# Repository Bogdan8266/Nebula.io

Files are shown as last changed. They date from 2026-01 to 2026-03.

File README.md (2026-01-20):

# <div align="center"> 🌌 NEBULA <br>  <sub>PORTABLE MODULAR CYBER-DECK PLATFORM</sub></div>  <div align="center">  <!-- BADGES: STATUS & INFO -->    <!-- BADGES: TECH STACK -->     

</div>
  
--- 
## 💀 BRIEFING
 **Nebula** is not just another ESP32 dev-board. It is an ultra-compact, modular handheld platform designed for advanced sensor monitoring, high-current PWM control, and researching airflow dynamics. 
 Built around the **ESP32-S3 WROOM-1**, featuring an Always-On **E-Ink display** and a complex sensor array. The device is powered by a high-density energy stack and encased in a custom shell. 
 > **Disclaimer:** This device includes high-current output drivers. It was designed for educational purposes, pneumatics research, and thermal control experiments. 
 ---
## 📷 3D Render

| 🥛 Semen White | 🍫 Shitty  Brown |
| :---: | :---: |
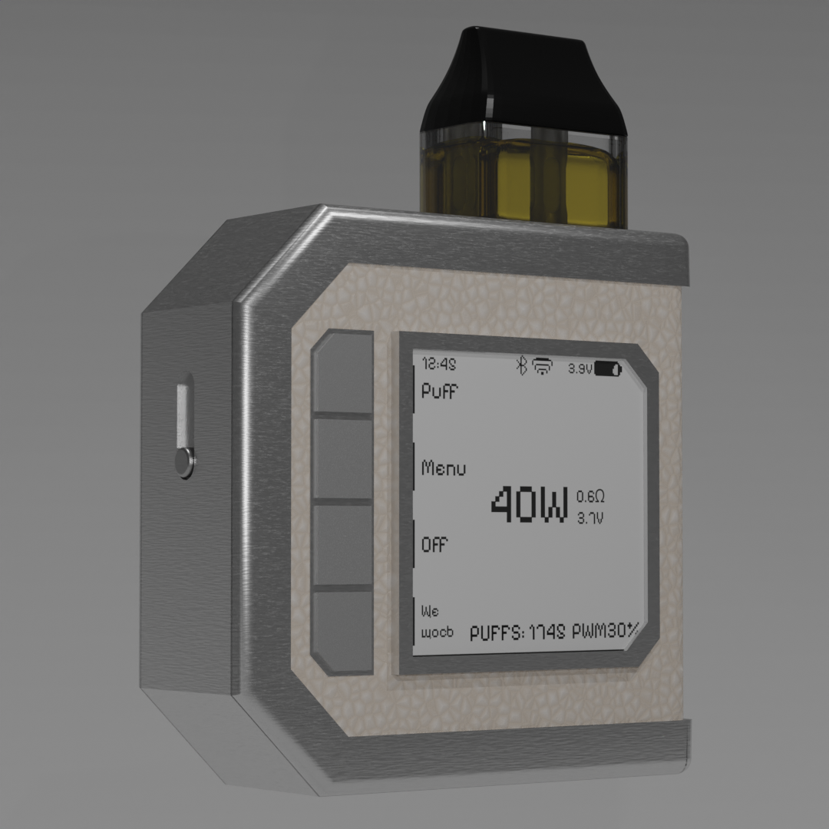
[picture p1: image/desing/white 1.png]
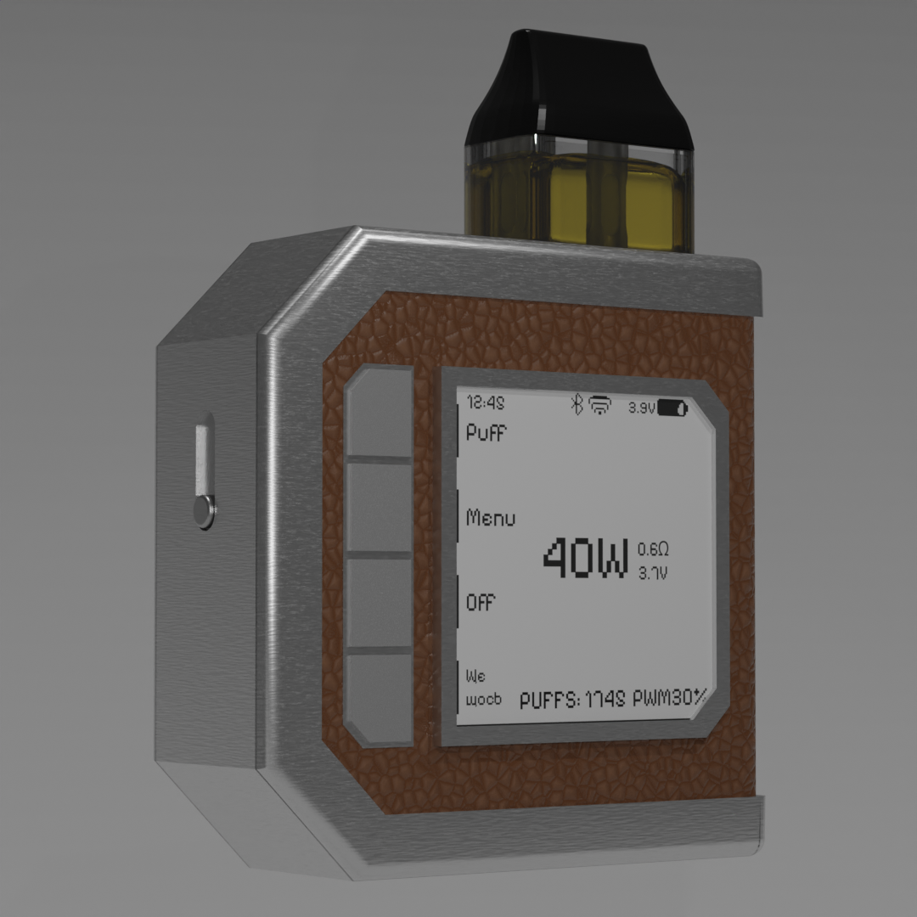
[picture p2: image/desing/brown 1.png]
|  |  |
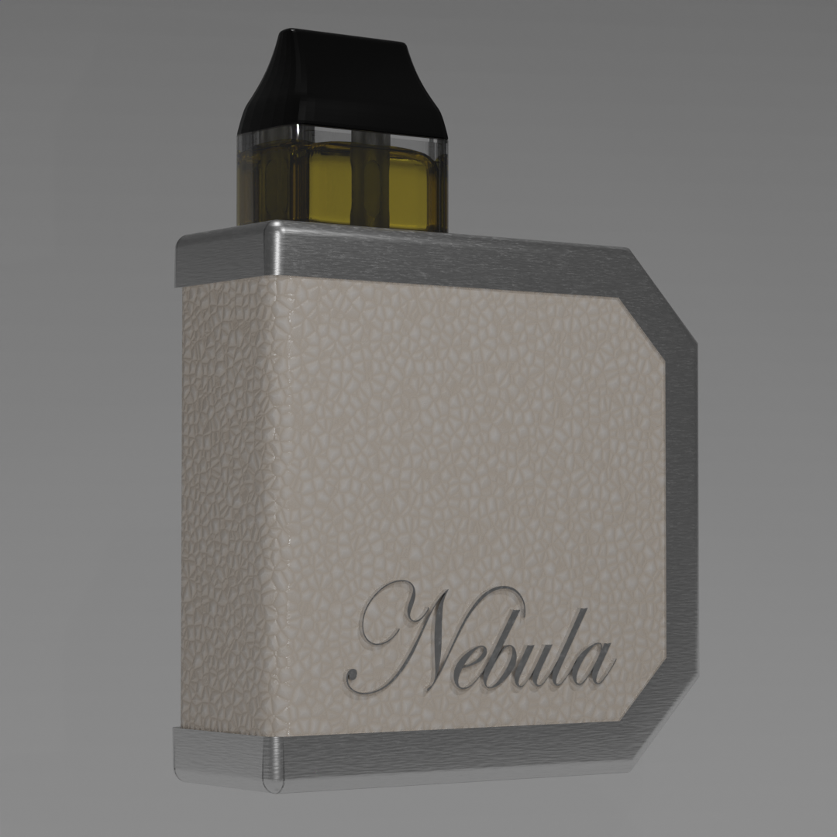
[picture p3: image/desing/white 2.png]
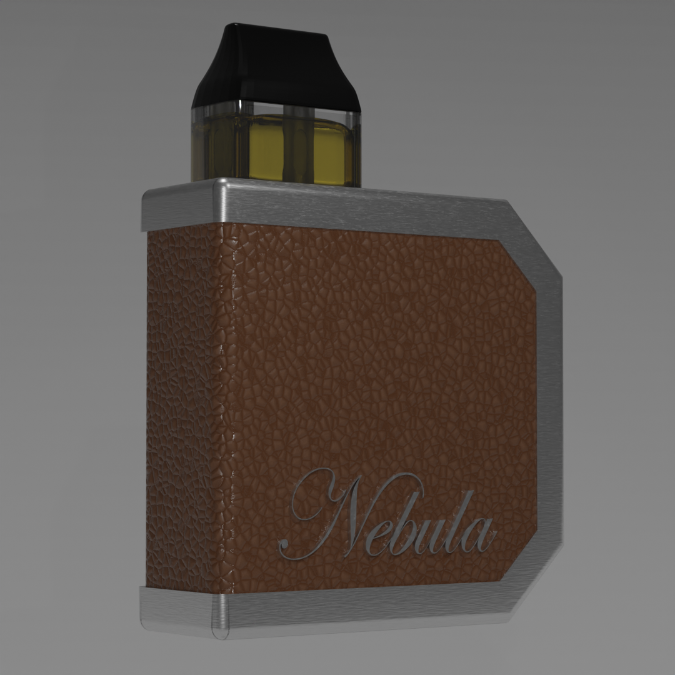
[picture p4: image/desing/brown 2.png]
|  |  |
 
  > *See full gallery in [`/media`](/media) folder.* 
  > ---
  
## 🔧 TECH SPECS 

| Component | Specification | Details |
| :--- | :--- | :--- |
| **🧠 MCU** | **ESP32-S3 WROOM-1** | Dual-Core @ 240MHz, WiFi + BLE 5.0 |
| **👁️ Display** | **1.54" E-Ink** | 200x200px, SSD1681 Driver |
| **🎮 Controls** | **Tactile & IMU** | 4x Switches + Motion/Gestures |
  
---
 ### 📡 Sensor Array (Inputs) 
 1. **Airflow / Pressure:** `BMP388` (Precision Barometric Sensor). Used for pneumatics triggers. 
 2.  **Inertial:** `MPU6050` (6-Axis Gyro + Accelerometer). 
 3.  **Power Mon:** `INA226` (Bi-directional Current/Power Monitor). High-side sensing. 
 4. **Triggers:** Custom analog pneumatic switch (Puff-sensor based). 
 5. **Internal:** Hall Effect & Temperature. 
 ---
 ### ⚡ Power System 
 * **Source:** Li-Po 651732 cell (20C High Drain). 
 * **Charging:** `TP4056` Linear Charger logic. 
   * **Protection:** Hardware voltage dividers + Software Low Voltage Cutoff (LVC). 
   * **Output Stage:** Dual **AO3400 (N-MOSFET)** setup for PWM control of heating elements. 
   * **Storage Gate:** **AO3401 (P-MOSFET)** for hard power-gating the MicroSD card (Deep Sleep optimization). 
---
### 💾 Storage 
* **Slot:** MicroSD (TF Card). 
  * **Format:** FAT32/exFAT. 
  * **Use Case:** Data logging (CSV), OTA Payloads, AOD Image Assets. 
---

## 📱 NEBULA COMPANION APP
*A bleeding-edge mobile application for telemetry and control.*

> [!WARNING]
> **System Requirements:** Android 16 (Baklava) or higher. Only for the brave.

* **Tech Stack:** `Native Android (Kotlin)` + `Jetpack Compose`
* **UI Design:** **Material 3 Expressive**
* **Key Features:** * 📡 **BLE Real-time telemetry** — Stay synced with your hardware.
    * 🎨 **Pixel-Art Editor** — Create custom E-Ink wallpapers.
    * 🚀 **Firmware OTA Updates** — Seamless wireless flashing.
    * 🔗 **"Cyber-Pairing" UX** — Next-gen device discovery.

---

## 🛠️ MANUFACTURE INFO
The PCB pushes the limits of DIY manufacturing with a focus on signal integrity:

| Parameter | Specification |
| :--- | :--- |
| **EDA Tool** | [EasyEDA](https://easyeda.com) |
| **PCB Stack** | **8-Layers** (Signal Integrity & Thermal focus) |
| **Finish** | ENIG (Immersion Gold) |
| **Special Features** | V-Cut daughterboard, Kelvin shunt connections |

### 📂 Technical Assets
* 📥 **[DOWNLOAD GERBER FILES](./hardware/gerbers)** — Ready for production.
* 📑 **[VIEW SCHEMATICS](./hardware/schematics)** — Detailed circuit diagrams.

---

## 📜 LICENSE
This project is open-source and available under the **MIT License**.

> Use it, hack it, build it. Just don't blame me if you burn your sensors. 🔥

---

<div align="center">
  
  <br>
  <i>"Any sufficiently advanced technology is indistinguishable from magic."</i>
  <br>
  <sub>© 1823 Nebula Project</sub>
</div>

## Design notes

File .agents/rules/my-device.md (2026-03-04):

---
trigger: always_on
---

PROJECT: NEBULA - Hi-Fi Modular Cyberdeck Player
SYSTEM CONTEXT & HARDWARE DEFINITION
Device Type: Ultra-compact, modular, handheld Hi-Fi audio player & cyberdeck. Aesthetic/Vibe: Cyberpunk, Industrial, Raw Tech, "Terminal" style UI, Dithering aesthetics, "Slow Tech" philosophy. Core Framework: Arduino (PlatformIO) on ESP32.

🧠 HARDWARE SPECIFICATIONS
1. MCU (Microcontroller):

Model: ESP32..
Key Feature: High-performance caching needed for audio decoding.
2. 👁️ Display (Visual Output):

Panel: 1.54" E-Ink (E-Paper) Display.
Driver: SSD1681.
Resolution: 200 x 200 pixels.
Interface: SPI (4-line SPI: SCK, MOSI, CS, DC, RST, BUSY).
Behavior: Supports Partial Refresh (fast) and Full Refresh. Static UI updates.
3. 💾 Storage (File System):

Media: MicroSD Card (SDXC supported, 128GB+).
Interface: SDMMC 1-bit Mode (Pins: CLK, CMD, D0).
Power Control: Dedicated LDO via GPIO to hard-reset the card for power saving.
File System: FAT32 (via FFat/SdFat) preferred for max compatibility.
4. 🎵 Audio Subsystem (High Fidelity):

DAC: PCM5102A (32-bit, 384kHz, I2S Interface).
Amp: MAX97220 (DirectDrive Headphone Amp, No Output Caps).
I2S Pins: BCK, LRCK, DIN.
Control Pins: XSMT (Soft Mute), SHDN (Amp Shutdown), FLT (Filter), DEMP (De-emphasis).
Headphone Jack: 3.5mm with "Anti-Loop" Hardware Detection (Pin 3 Detect logic).
5. 📡 Sensors & Inputs:

IMU: MPU6050 (Gyro + Accel) via I2C. Used for "Raise to Wake".
Barometer: BMP388 (Precision Pressure) via I2C.
Light Sensor: GL5528 Photoresistor on GPIO13 (ADC2). Used for "Pocket Mode".
Buttons: 4x Tactile Switches connected via ADC Resistor Ladder to a single Analog Pin.
Feedback: LRA Haptic Motor (via L9110S driver).
6. ⚡ Power System:

Battery: Li-Po 1S (3.7V - 4.2V).
Architecture: 3x Discrete XC6220 LDOs (Main, Audio, SD) individually controlled via GPIOs for Deep Sleep optimization.
Charging: IP2312 (High efficiency switching charger).
💻 CURRENT DEVELOPMENT FOCUS: PHASE 1
Goal: Initialize Core System, Display, and Storage. No Audio/Sensors logic yet.

Requirements for Code:

Display: Use GxEPD2 library. Setup for SSD1681 200x200. Implement a "Boot Screen" with a terminal-style loading log (e.g., "MOUNTING SD... OK").
Storage: Initialize SD card in SDMMC 1-bit mode. List files in root directory to Serial Monitor and Display.
UI Style: Monospaced fonts, black background/white text (inverted console style). No animations, discrete updates only.

🎨 UI & UX PHILOSOPHY (The Vibe)
AOD (Always On Display): When sleeping, show a static high-contrast image (Dithered Album Art) + QR Code with Owner Info.
Now Playing: Large Dithered Album Art (background or center), Bold Typography, Status Bar (Battery V/%, Icons).
Navigation: Folder-based structure. Simple lists.

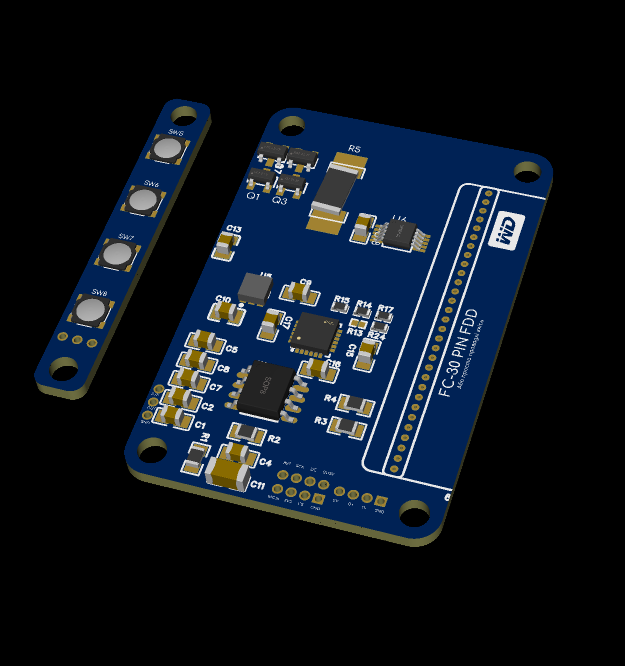
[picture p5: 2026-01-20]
image/PCB/PCB2.png

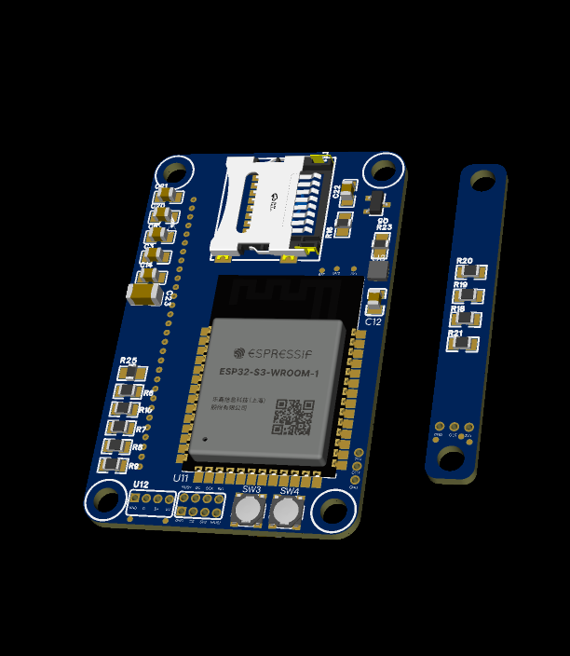
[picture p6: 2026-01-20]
image/PCB/PCB1.png

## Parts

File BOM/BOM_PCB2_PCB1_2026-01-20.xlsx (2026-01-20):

No. | Quantity | Comment | Designator | Footprint | Value | Manufacturer Part | Manufacturer | Supplier Part | Supplier
1 | 3 | 10u | C1,C8,C20 | C0805
2 | 5 | 100n | C2,C3,C6,C7,C21 | C0805
3 | 2 | 10uF | C4,C11 | C0805
4 | 2 | 1u | C5,C23 | C0805
5 | 2 | 10u | C9,C10 | C0805 |  | CL10A105KB8NNNC | SAMSUNG | C15849 | LCSC
6 | 5 | 0.1uF | C12,C14,C15,C17,C18 | C0805
7 | 1 | 1uF | C13 | C0805
8 | 1 | 2200pF | C16 | C0805
9 | 1 | 100nF | C22 | C0805 | 100nF
10 | 4 | AO3400A | Q1,Q3,Q6,Q7 | SOT-23-3_L2.9-W1.3-P1.90-LS2.4-BR |  | AO3400A | AOS | C20917 | LCSC
11 | 1 | AO3401 | Q5 | SOT-23-3_L2.9-W1.4-P1.90-LS2.5-BR |  | AO3401 | GMIC(绿微) | C53261043 | LCSC
12 | 4 | 10k | R1,R4,R23,R25 | R0805
13 | 1 | 1.2k | R2 | R0805
14 | 1 | 100 | R3 | R0805
15 | 1 | 0.002 | R5 | R2512
16 | 2 | 100k | R6,R10 | R0805
17 | 2 | 4.7K | R7,R8 | R0805
18 | 2 | 10K | R9,R16 | R0805
19 | 5 | 0 | R13,R14,R15,R17,R24 | 0402 | 0
20 | 2 | 10K | R18,R21 | R0805 | 10K
21 | 1 | 1K | R19 | R0805 | 1K
22 | 1 | 4.7K | R20 | R0805 | 4.7K
23 | 6 | SWITCH-3.7x3.7x0.35_SMD | SW3,SW4,SW5,SW6,SW7,SW8 | SW-SMD_4P-L3.7-W3.7-P2.75-LS3.7 |  | SWITCH-3.7x3.7x0.35_SMD | BBJ | E19636 | EasyEDA
24 | 1 | TF-CARD XG8P H1.5 | TF1 | TF-SMD_TF-CARD-XG8P-H1.5 |  | TF-CARD XG8P H1.5 | SHOU HAN(首韩) | C7529392 | LCSC
25 | 1 | TP4056-MS | U1 | SOP-8_L4.9-W3.9-P1.27-LS6.0-TL-EP |  | TP4056-MS | MSKSEMI(美森科) | C7473158 | LCSC
26 | 1 | ESP32-S3-WROOM-1 | U2 | ESP32-S3-WROOM-1 |  | ESP32-S3-WROOM-1 | Espressif Systems | ESP32-S3-WROOM-1
27 | 1 | BMP388 | U3 | SENSORM-SMD_BMP388 |  | BMP388 | Bosch(博世) | C779278 | LCSC
28 | 1 | MPU6050_C9900042518 | U4 | QFN-24_L4.0-W4.0-P0.50-BL |  | MPU6050 | null | C9900042518 | LCSC
29 | 1 | XC6220B331MR | U5 | SOT-23-5_L2.9-W1.6-P0.95-LS2.8-BR |  | XC6220B331MR | TECH PUBLIC(台舟) | C3040644 | LCSC
30 | 1 | INA226AQDGSRQ1 | U6 | VSSOP-10_L3.0-W3.0-P0.50-LS4.9-BL |  | INA226AQDGSRQ1 | TI(德州仪器) | C2653835 | LCSC
31 | 1 | 26PIN-dff | U9 | 26PIN-FDD
32 | 1 | Puff sensor | U10 | Puff sensor
33 | 1 | HDR-TH_8P-P0.6 | U11 | HDR-TH_8P-P0.6
34 | 1 | USB-CONNECTOR-OUT | U12 | USB-CONNECTOR-4-PIN

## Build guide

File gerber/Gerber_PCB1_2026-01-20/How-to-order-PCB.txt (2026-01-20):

How to Order PCB

Please refer to:
https://prodocs.easyeda.com/en/pcb/order-order-pcb/index.html

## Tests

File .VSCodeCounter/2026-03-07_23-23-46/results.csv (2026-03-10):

filename | "language" | "C++" | "comment" | "blank" | "total"
/home/bodya/Documents/PlatformIO/Projects/Nebula Os/src/audio/AudioPlayer.h | "C++" | 165 | 3 | 29 | 197
/home/bodya/Documents/PlatformIO/Projects/Nebula Os/src/db/ArtExtractor.h | "C++" | 133 | 11 | 22 | 166
/home/bodya/Documents/PlatformIO/Projects/Nebula Os/src/db/MediaDB.h | "C++" | 158 | 12 | 19 | 189
/home/bodya/Documents/PlatformIO/Projects/Nebula Os/src/db/MediaScanner.h | "C++" | 137 | 15 | 24 | 176
/home/bodya/Documents/PlatformIO/Projects/Nebula Os/src/db/MetaReader.h | "C++" | 249 | 26 | 33 | 308
/home/bodya/Documents/PlatformIO/Projects/Nebula Os/src/db/SettingsManager.h | "C++" | 122 | 3 | 17 | 142
/home/bodya/Documents/PlatformIO/Projects/Nebula Os/src/input/SerialInput.h | "C++" | 22 | 1 | 3 | 26
/home/bodya/Documents/PlatformIO/Projects/Nebula Os/src/led/LEDManager.cpp | "C++" | 98 | 11 | 23 | 132
/home/bodya/Documents/PlatformIO/Projects/Nebula Os/src/led/LEDManager.h | "C++" | 34 | 1 | 10 | 45
/home/bodya/Documents/PlatformIO/Projects/Nebula Os/src/main.cpp | "C++" | 796 | 150 | 144 | 1090
/home/bodya/Documents/PlatformIO/Projects/Nebula Os/src/sensors/MPU6050Manager.h | "C++" | 90 | 7 | 17 | 114
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

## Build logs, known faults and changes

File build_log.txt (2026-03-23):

Processing esp32s3 (platform: espressif32; board: esp32-s3-devkitc-1; framework: arduino)
--------------------------------------------------------------------------------
Tool Manager: Could not parse manifest -> Expecting value: line 1 column 1 (char 0)
Tool Manager: Could not parse manifest -> Expecting value: line 1 column 1 (char 0)
Tool Manager: Could not parse manifest -> Expecting value: line 1 column 1 (char 0)
Tool Manager: Could not parse manifest -> Expecting value: line 1 column 1 (char 0)
Tool Manager: Could not parse manifest -> Expecting value: line 1 column 1 (char 0)
Tool Manager: Could not parse manifest -> Expecting value: line 1 column 1 (char 0)
Tool Manager: Could not parse manifest -> Expecting value: line 1 column 1 (char 0)
Tool Manager: Could not parse manifest -> Expecting value: line 1 column 1 (char 0)
Tool Manager: Could not parse manifest -> Expecting value: line 1 column 1 (char 0)
Tool Manager: Could not parse manifest -> Expecting value: line 1 column 1 (char 0)
Tool Manager: Could not parse manifest -> Expecting value: line 1 column 1 (char 0)
Tool Manager: Could not parse manifest -> Expecting value: line 1 column 1 (char 0)
Verbose mode can be enabled via `-v, --verbose` option
Tool Manager: Could not parse manifest -> Expecting value: line 1 column 1 (char 0)
CONFIGURATION: https://docs.platformio.org/page/boards/espressif32/esp32-s3-devkitc-1.html
PLATFORM: Espressif 32 (6.12.0) > Espressif ESP32-S3-DevKitC-1-N8 (8 MB QD, No PSRAM)
HARDWARE: ESP32S3 240MHz, 320KB RAM, 16MB Flash
DEBUG: Current (esp-builtin) On-board (esp-builtin) External (cmsis-dap, esp-bridge, esp-prog, iot-bus-jtag, jlink, minimodule, olimex-arm-usb-ocd, olimex-arm-usb-ocd-h, olimex-arm-usb-tiny-h, olimex-jtag-tiny, tumpa)
PACKAGES: 
 - framework-arduinoespressif32 @ 3.20017.241212+sha.dcc1105b 
 - tool-esptoolpy @ 2.40900.250804 (4.9.0) 
 - tool-openocd-esp32 @ 2.1100.20220706 (11.0) 
 - toolchain-riscv32-esp @ 8.4.0+2021r2-patch5 
 - toolchain-xtensa-esp32s3 @ 8.4.0+2021r2-patch5
LDF: Library Dependency Finder -> https://bit.ly/configure-pio-ldf
LDF Modes: Finder ~ chain, Compatibility ~ soft
Found 45 compatible libraries
Scanning dependencies...
Dependency Graph
|-- Adafruit BusIO @ 1.17.4
|-- GxEPD2 @ 1.6.7
|-- Adafruit GFX Library @ 1.12.5
|-- U8g2_for_Adafruit_GFX @ 1.8.0
|-- JPEGDEC @ 1.8.4
|-- audio-tools @ 1.2.2+sha.b520706
|-- libfoxenflac @ 1.0.0+sha.4cfa2f5
|-- ESP32-A2DP @ 1.8.9+sha.80d1041
|-- MPU6050 @ 1.4.4
|-- FastLED @ 3.10.3
|-- QRCode @ 0.0.1
|-- ArduinoOTA @ 2.0.0
|-- FS @ 2.0.0
|-- SD_MMC @ 2.0.0
|-- SPI @ 2.0.0
|-- WebServer @ 2.0.0
|-- WiFi @ 2.0.0
|-- Wire @ 2.0.0
Building in release mode
Compiling .pio/build/esp32s3/src/main.cpp.o
<command-line>: warning: "ARDUINO_USB_MODE" redefined
<command-line>: note: this is the location of the previous definition
In file included from .pio/libdeps/esp32s3/ESP32-A2DP/src/BluetoothA2DPSink.h:17,
                 from src/bluetooth/BluetoothManager.h:4,
                 from src/main.cpp:37:
.pio/libdeps/esp32s3/ESP32-A2DP/src/BluetoothA2DPCommon.h:33:4: error: #error "Please read the ESP32-A2DP Wiki about the supported Platforms!"
 #  error "Please read the ESP32-A2DP Wiki about the supported Platforms!"
    ^~~~~
Compiling .pio/build/esp32s3/lib670/GxEPD2/epd3c/GxEPD2_583c.cpp.o
Compiling .pio/build/esp32s3/lib670/GxEPD2/epd3c/GxEPD2_583c_Z83.cpp.o
<command-line>: warning: "ARDUINO_USB_MODE" redefined
<command-line>: note: this is the location of the previous definition
Compiling .pio/build/esp32s3/lib670/GxEPD2/epd3c/GxEPD2_750c.cpp.o
<command-line>: warning: "ARDUINO_USB_MODE" redefined
<command-line>: note: this is the location of the previous definition
Compiling .pio/build/esp32s3/lib670/GxEPD2/epd3c/GxEPD2_750c_GDEW075Z08.cpp.o
<command-line>: warning: "ARDUINO_USB_MODE" redefined
<command-line>: note: this is the location of the previous definition
Compiling .pio/build/esp32s3/lib670/GxEPD2/epd3c/GxEPD2_750c_Z08.cpp.o
<command-line>: warning: "ARDUINO_USB_MODE" redefined
<command-line>: note: this is the location of the previous definition
Compiling .pio/build/esp32s3/lib670/GxEPD2/epd3c/GxEPD2_750c_Z90.cpp.o
<command-line>: warning: "ARDUINO_USB_MODE" redefined
<command-line>: note: this is the location of the previous definition
Compiling .pio/build/esp32s3/lib670/GxEPD2/epd4c/GxEPD2_1160c_GDEY116F51.cpp.o
<command-line>: warning: "ARDUINO_USB_MODE" redefined
<command-line>: note: this is the location of the previous definition
Compiling .pio/build/esp32s3/lib670/GxEPD2/epd4c/GxEPD2_154c_GDEM0154F51H.cpp.o
<command-line>: warning: "ARDUINO_USB_MODE" redefined
<command-line>: note: this is the location of the previous definition
Compiling .pio/build/esp32s3/lib670/GxEPD2/epd4c/GxEPD2_213c_GDEY0213F51.cpp.o
<command-line>: warning: "ARDUINO_USB_MODE" redefined
<command-line>: note: this is the location of the previous definition
Compiling .pio/build/esp32s3/lib670/GxEPD2/epd4c/GxEPD2_266c_GDEY0266F51H.cpp.o
<command-line>: warning: "ARDUINO_USB_MODE" redefined
<command-line>: note: this is the location of the previous definition
<command-line>: warning: "ARDUINO_USB_MODE" redefined
<command-line>: note: this is the location of the previous definition
Compiling .pio/build/esp32s3/lib670/GxEPD2/epd4c/GxEPD2_290c_GDEY029F51H.cpp.o
Compiling .pio/build/esp32s3/lib670/GxEPD2/epd4c/GxEPD2_300c.cpp.o
<command-line>: warning: "ARDUINO_USB_MODE" redefined
<command-line>: note: this is the location of the previous definition
Compiling .pio/build/esp32s3/lib670/GxEPD2/epd4c/GxEPD2_350c_GDEM035F51.cpp.o
<command-line>: warning: "ARDUINO_USB_MODE" redefined
<command-line>: note: this is the location of the previous definition
Compiling .pio/build/esp32s3/lib670/GxEPD2/epd4c/GxEPD2_397c_GDEM0397F81.cpp.o
<command-line>: warning: "ARDUINO_USB_MODE" redefined
<command-line>: note: this is the location of the previous definition
Compiling .pio/build/esp32s3/lib670/GxEPD2/epd4c/GxEPD2_420c_GDEY0420F51.cpp.o
<command-line>: warning: "ARDUINO_USB_MODE" redefined
<command-line>: note: this is the location of the previous definition
Compiling .pio/build/esp32s3/lib670/GxEPD2/epd4c/GxEPD2_437c.cpp.o
<command-line>: warning: "ARDUINO_USB_MODE" redefined
<command-line>: note: this is the location of the previous definition
Compiling .pio/build/esp32s3/lib670/GxEPD2/epd4c/GxEPD2_579c_GDEY0579F51.cpp.o
<command-line>: warning: "ARDUINO_USB_MODE" redefined
<command-line>: note: this is the location of the previous definition
Compiling .pio/build/esp32s3/lib670/GxEPD2/epd4c/GxEPD2_750c_GDEM075F52.cpp.o
<command-line>: warning: "ARDUINO_USB_MODE" redefined
<command-line>: note: this is the location of the previous definition
Compiling .pio/build/esp32s3/lib670/GxEPD2/epd7c/GxEPD2_565c.cpp.o
<command-line>: warning: "ARDUINO_USB_MODE" redefined
<command-line>: note: this is the location of the previous definition
Compiling .pio/build/esp32s3/lib670/GxEPD2/epd7c/GxEPD2_565c_GDEP0565D90.cpp.o
<command-line>: warning: "ARDUINO_USB_MODE" redefined
<command-line>: note: this is the location of the previous definition
Compiling .pio/build/esp32s3/lib670/GxEPD2/epd7c/GxEPD2_730c_ACeP_730.cpp.o
<command-line>: warning: "ARDUINO_USB_MODE" redefined
<command-line>: note: this is the location of the previous definition
<command-line>: warning: "ARDUINO_USB_MODE" redefined
<command-line>: note: this is the location of the previous definition
Compiling .pio/build/esp32s3/lib670/GxEPD2/epd7c/GxEPD2_730c_GDEP073E01.cpp.o
Compiling .pio/build/esp32s3/lib670/GxEPD2/epd7c/GxEPD2_730c_GDEY073D46.cpp.o
<command-line>: warning: "ARDUINO_USB_MODE" redefined
<command-line>: note: this is the location of the previous definition
<command-line>: warning: "ARDUINO_USB_MODE" redefined
<command-line>: note: this is the location of the previous definition
Compiling .pio/build/esp32s3/lib670/GxEPD2/gdem/GxEPD2_1020_GDEM102T91.cpp.o
<command-line>: warning: "ARDUINO_USB_MODE" redefined
<command-line>: note: this is the location of the previous definition
Compiling .pio/build/esp32s3/lib670/GxEPD2/gdem/GxEPD2_1085_GDEM1085T51.cpp.o
In file included from src/main.cpp:37:
src/bluetooth/BluetoothManager.h:68:5: error: 'BluetoothA2DPSink' does not name a type; did you mean 'BluetoothSettings'?
     BluetoothA2DPSink _a2dp_sink;
     ^~~~~~~~~~~~~~~~~
     BluetoothSettings
src/bluetooth/BluetoothManager.h: In member function 'void BluetoothManager::start()':
src/bluetooth/BluetoothManager.h:37:9: error: '_a2dp_sink' was not declared in this scope
         _a2dp_sink.set_pin_config(pin_config);
         ^~~~~~~~~~
Compiling .pio/build/esp32s3/lib670/GxEPD2/gdem/GxEPD2_1330_GDEM133T91.cpp.o
src/bluetooth/BluetoothManager.h: In member function 'void BluetoothManager::stop()':
src/bluetooth/BluetoothManager.h:52:9: error: '_a2dp_sink' was not declared in this scope
         _a2dp_sink.end();
         ^~~~~~~~~~
<command-line>: warning: "ARDUINO_USB_MODE" redefined
<command-line>: note: this is the location of the previous definition
src/bluetooth/BluetoothManager.h: In member function 'void BluetoothManager::setVolume(float)':
src/bluetooth/BluetoothManager.h:62:13: error: '_a2dp_sink' was not declared in this scope
             _a2dp_sink.set_volume(v * 127);
             ^~~~~~~~~~
<command-line>: warning: "ARDUINO_USB_MODE" redefined
<command-line>: note: this is the location of the previous definition
Compiling .pio/build/esp32s3/lib670/GxEPD2/gdem/GxEPD2_397_GDEM0397T81.cpp.o
<command-line>: warning: "ARDUINO_USB_MODE" redefined
<command-line>: note: this is the location of the previous definition
Compiling .pio/build/esp32s3/lib670/GxEPD2/gdem3c/GxEPD2_1330c_GDEM133Z91.cpp.o
<command-line>: warning: "ARDUINO_USB_MODE" redefined
<command-line>: note: this is the location of the previous definition
Compiling .pio/build/esp32s3/lib670/GxEPD2/gdeq/GxEPD2_310_GDEQ031T10.cpp.o
<command-line>: warning: "ARDUINO_USB_MODE" redefined
<command-line>: note: this is the location of the previous definition
Compiling .pio/build/esp32s3/lib670/GxEPD2/gdeq/GxEPD2_426_GDEQ0426T82.cpp.o
<command-line>: warning: "ARDUINO_USB_MODE" redefined
<command-line>: note: this is the location of the previous definition
Compiling .pio/build/esp32s3/lib670/GxEPD2/gdeq/GxEPD2_583_GDEQ0583T31.cpp.o
<command-line>: warning: "ARDUINO_USB_MODE" redefined
<command-line>: note: this is the location of the previous definition
Compiling .pio/build/esp32s3/lib670/GxEPD2/gdeq3c/GxEPD2_583c_GDEQ0583Z31.cpp.o
Compiling .pio/build/esp32s3/lib670/GxEPD2/gdey/GxEPD2_154_GDEY0154D67.cpp.o
<command-line>: warning: "ARDUINO_USB_MODE" redefined
<command-line>: note: this is the location of the previous definition
<command-line>: warning: "ARDUINO_USB_MODE" redefined
<command-line>: note: this is the location of the previous definition
Compiling .pio/build/esp32s3/lib670/GxEPD2/gdey/GxEPD2_213_GDEY0213B74.cpp.o
Compiling .pio/build/esp32s3/lib670/GxEPD2/gdey/GxEPD2_266_GDEY0266T90.cpp.o
<command-line>: warning: "ARDUINO_USB_MODE" redefined
<command-line>: note: this is the location of the previous definition
<command-line>: warning: "ARDUINO_USB_MODE" redefined
<command-line>: note: this is the location of the previous definition
Compiling .pio/build/esp32s3/lib670/GxEPD2/gdey/GxEPD2_270_GDEY027T91.cpp.o
Compiling .pio/build/esp32s3/lib670/GxEPD2/gdey/GxEPD2_290_GDEY029T71H.cpp.o
<command-line>: warning: "ARDUINO_USB_MODE" redefined
<command-line>: note: this is the location of the previous definition
<command-line>: warning: "ARDUINO_USB_MODE" redefined
<command-line>: note: this is the location of the previous definition
Compiling .pio/build/esp32s3/lib670/GxEPD2/gdey/GxEPD2_290_GDEY029T94.cpp.o
<command-line>: warning: "ARDUINO_USB_MODE" redefined
<command-line>: note: this is the location of the previous definition
Compiling .pio/build/esp32s3/lib670/GxEPD2/gdey/GxEPD2_370_GDEY037T03.cpp.o
Compiling .pio/build/esp32s3/lib670/GxEPD2/gdey/GxEPD2_420_GDEY042T81.cpp.o
<command-line>: warning: "ARDUINO_USB_MODE" redefined
<command-line>: note: this is the location of the previous definition
Compiling .pio/build/esp32s3/lib670/GxEPD2/gdey/GxEPD2_579_GDEY0579T93.cpp.o
<command-line>: warning: "ARDUINO_USB_MODE" redefined
<command-line>: note: this is the location of the previous definition
Compiling .pio/build/esp32s3/lib670/GxEPD2/gdey/GxEPD2_750_GDEY075T7.cpp.o
<command-line>: warning: "ARDUINO_USB_MODE" redefined
<command-line>: note: this is the location of the previous definition
<command-line>: warning: "ARDUINO_USB_MODE" redefined
<command-line>: note: this is the location of the previous definition
Compiling .pio/build/esp32s3/lib670/GxEPD2/gdey3c/GxEPD2_1160c_GDEY116Z91.cpp.o
Compiling .pio/build/esp32s3/lib670/GxEPD2/gdey3c/GxEPD2_420c_GDEY042Z98.cpp.o
<command-line>: warning: "ARDUINO_USB_MODE" redefined
<command-line>: note: this is the location of the previous definition
Compiling .pio/build/esp32s3/lib670/GxEPD2/gdey3c/GxEPD2_579c_GDEY0579Z93.cpp.o
<command-line>: warning: "ARDUINO_USB_MODE" redefined
<command-line>: note: this is the location of the previous definition
Compiling .pio/build/esp32s3/lib670/GxEPD2/gdey3c/GxEPD2_750c_GDEY075Z08.cpp.o
<command-line>: warning: "ARDUINO_USB_MODE" redefined
<command-line>: note: this is the location of the previous definition
<command-line>: warning: "ARDUINO_USB_MODE" redefined
<command-line>: note: this is the location of the previous definition
Compiling .pio/build/esp32s3/lib670/GxEPD2/it8951/GxEPD2_it103_1872x1404.cpp.o
Compiling .pio/build/esp32s3/lib670/GxEPD2/it8951/GxEPD2_it60.cpp.o
<command-line>: warning: "ARDUINO_USB_MODE" redefined
<command-line>: note: this is the location of the previous definition
<command-line>: warning: "ARDUINO_USB_MODE" redefined
<command-line>: note: this is the location of the previous definition
Compiling .pio/build/esp32s3/lib670/GxEPD2/it8951/GxEPD2_it60_1448x1072.cpp.o
Compiling .pio/build/esp32s3/lib670/GxEPD2/it8951/GxEPD2_it78_1872x1404.cpp.o
<command-line>: warning: "ARDUINO_USB_MODE" redefined
<command-line>: note: this is the location of the previous definition
Compiling .pio/build/esp32s3/lib670/GxEPD2/other/GxEPD2_420_GYE042A87.cpp.o
<command-line>: warning: "ARDUINO_USB_MODE" redefined
<command-line>: note: this is the location of the previous definition
<command-line>: warning: "ARDUINO_USB_MODE" redefined
<command-line>: note: this is the location of the previous definition
Compiling .pio/build/esp32s3/lib670/GxEPD2/other/GxEPD2_420_SE0420NQ04.cpp.o
<command-line>: warning: "ARDUINO_USB_MODE" redefined
<command-line>: note: this is the location of the previous definition
Compiling .pio/build/esp32s3/lib550/U8g2_for_Adafruit_GFX/U8g2_for_Adafruit_GFX.cpp.o
*** [.pio/build/esp32s3/src/main.cpp.o] Error 1
<command-line>: warning: "ARDUINO_USB_MODE" redefined
<command-line>: note: this is the location of the previous definition
========================== [FAILED] Took 8.62 seconds ==========================

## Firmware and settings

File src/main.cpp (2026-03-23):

/**
 * ╔══════════════════════════════════════════════════╗
 * ║           N E B U L A   O S   v0.1              ║
 * ║    Hi-Fi Modular Cyberdeck Player Firmware       ║
 * ║    Phase 3: Library Menu + Album Art             ║
 * ╚══════════════════════════════════════════════════╝
 *
 * Controls (Serial Monitor 115200):
 *   Menu:       1=UP  2=SELECT  3=DOWN  4=BACK
 *   NowPlaying: 1=PREV  2=PLAY  3=NEXT  4=→Menu
 *   r = Force rescan    d = Dump library
 */

#include <Arduino.h>
#include <SPI.h>
#include <WiFi.h>
#include <WebServer.h>
#include <ArduinoOTA.h>
#include <GxEPD2_BW.h>
#include <Fonts/FreeMonoBold9pt7b.h>
#include <Fonts/FreeMono9pt7b.h>
#include <FS.h>
#include <SD_MMC.h>

#include "input/SerialInput.h"
#include "ui/StatusWidget.h"
#include "ui/NowPlaying.h"
#include "ui/MenuScene.h"
#include "ui/CoverFlowScene.h"
#include "ui/ArtRenderer.h"
#include "ui/MainMenuScene.h"
#include "db/MediaDB.h"
#include "db/MediaScanner.h"
#include "web/WebManager.h"
#include "web/UsbMscManager.h"
#include "audio/AudioPlayer.h"


#include "ui/SettingsScene.h"
#include "ui/SensorsScene.h"
#include "db/SettingsManager.h"
#include "sensors/MPU6050Manager.h"
#include "led/LEDManager.h"
#include "ui/FileExplorerScene.h"
#include "wifi/WiFiScanner.h"
#include "ui/WiFiScene.h"

// ── Wi-Fi ────────────────────────────────────────────────────────
#define WIFI_SSID "Xiaomi_14F8"
#define WIFI_PASS "123456789042"

// ── Pins ─────────────────────────────────────────────────────────
#define EPD_CS    10
#define EPD_DC    17
#define EPD_RST   16
#define EPD_BUSY  18

// ── Audio/Power Placeholders (Future PCB) ────────────────────────
// #define DAC_XSMT  XX // Soft Mute
// #define LDO_EN    XX // 3.3V LDO for Audio/SD

#define SD_MMC_CLK 14
#define SD_MMC_CMD 15
#define SD_MMC_D0  2

// ── Display ───────────────────────────────────────────────────────
using Display = GxEPD2_BW<GxEPD2_154_D67, GxEPD2_154_D67::HEIGHT>;
Display display(GxEPD2_154_D67(EPD_CS, EPD_DC, EPD_RST, EPD_BUSY));

// ── SD + DB ───────────────────────────────────────────────────────
fs::FS&      sd = SD_MMC;
MediaDB      mediaDB;
MediaScanner scanner;

// ── Settings ──────────────────────────────────────────────────────
SystemSettings sysSettings;
SettingsScene  settingsScene;
SensorsScene   sensorsScene;
FileExplorerScene explorerScene;
MPU6050Manager mpuManager;

// ── Scenes ────────────────────────────────────────────────────────
MenuScene<Display>    menu;
CoverFlowScene<Display> coverFlow;
MainMenuScene<Display, fs::FS> mainMenu;
StatusWidget          systemStatus;
NowPlaying<Display>   nowPlaying(display);

enum class AppState { BOOT, MAIN_MENU, COVER_FLOW, SONG_LIST, NOW_PLAYING, SETTINGS, USB_SYNC, SENSORS, FILE_EXPLORER, WIFI_SCANNER };
AppState appState = AppState::BOOT;
NebulaPlayer audioPlayer;
WebManager   webManager(sd);
WiFiScanner  wifiScanner;
WiFiScene    wifiScene;

// Dynamic coloring based on settings
#define CL_BG (sysSettings.display.inverted ? GxEPD_BLACK : GxEPD_WHITE)
#define CL_FG (sysSettings.display.inverted ? GxEPD_WHITE : GxEPD_BLACK)

// К-ть треків у поточному альбомі та поточний індекс для PREV/NEXT
static TrackRecord  currentAlbumTracks[8]; // Reduced from 16 to save 4KB
static uint16_t     currentAlbumTrackCount = 0;
static int16_t      currentTrackIdx        = -1;

// ─────────────────────────────────────────────────────────────────
//  Memory Management for NowPlaying Background
// ─────────────────────────────────────────────────────────────────
static uint8_t* currentNpBgBitmap = nullptr;
static uint32_t trackStartTime = 0;
static uint32_t totalPauseTime = 0;
static uint32_t pauseStartTime = 0;

// ─────────────────────────────────────────────────────────────────
//  Waveform LUT for SSD1681 - Fast vs Quality
// ─────────────────────────────────────────────────────────────────
// Fast LUT: Minimal phases, short times = fast refresh
// Quality LUT: Full phases, proper times = best image quality

// Standard full waveform (from GxEPD2 library, optimized)
static const uint8_t waveformFull[] = {
    // VS settings for each phase (48 phases x 4 LUTs x 2 bits = 384 bits = 48 bytes)
    0x00, 0x00, 0x00, 0x00, 0x00, 0x00, 0x00, 0x00,
    0x00, 0x00, 0x00, 0x00, 0x00, 0x00, 0x00, 0x00,
    0x00, 0x00, 0x00, 0x00, 0x00, 0x00, 0x00, 0x00,
    0x00, 0x00, 0x00, 0x00, 0x00, 0x00, 0x00, 0x00,
    0x00, 0x00, 0x00, 0x00, 0x00, 0x00, 0x00, 0x00,
    0x00, 0x00, 0x00, 0x00, 0x00, 0x00, 0x00, 0x00,
    // TP (time per phase) - 48 bytes
    0x01, 0x01, 0x01, 0x01, 0x02, 0x02, 0x04, 0x04,
    0x08, 0x08, 0x10, 0x10, 0x20, 0x20, 0x40, 0x40,
    0x80, 0x80, 0x00, 0x00, 0x00, 0x00, 0x00, 0x00,
    0x00, 0x00, 0x00, 0x00, 0x00, 0x00, 0x00, 0x00,
    0x00, 0x00, 0x00, 0x00, 0x00, 0x00, 0x00, 0x00,
    0x00, 0x00, 0x00, 0x00, 0x00, 0x00, 0x00, 0x00,
    // RP (repeat count) - 12 bytes
    0x00, 0x00, 0x00, 0x00, 0x00, 0x00, 0x00, 0x00,
    0x00, 0x00, 0x00, 0x00,
    // SR (state repeat) - 24 bytes  
    0x01, 0x01, 0x01, 0x01, 0x01, 0x01, 0x01, 0x01,
    0x01, 0x01, 0x01, 0x01, 0x01, 0x01, 0x01, 0x01,
    0x01, 0x01, 0x01, 0x01, 0x01, 0x01, 0x01, 0x01,
    // FR (frame rate) - 12 bytes
    0x00, 0x00, 0x00, 0x00, 0x00, 0x00, 0x00, 0x00,
    0x00, 0x00, 0x00, 0x00,
    // XON - 3 bytes
    0x00, 0x00, 0x00,
    // EOPT, Gate/Source/VCOM - 5 bytes
    0x02, 0x00, 0x3F, 0x00, 0x00
};

// Fast waveform - fewer phases, shorter times
static const uint8_t waveformFast[] = {
    // VS settings - minimal
    0x00, 0x00, 0x00, 0x00, 0x00, 0x00, 0x00, 0x00,
    0x00, 0x00, 0x00, 0x00, 0x00, 0x00, 0x00, 0x00,
    0x00, 0x00, 0x00, 0x00, 0x00, 0x00, 0x00, 0x00,
    0x00, 0x00, 0x00, 0x00, 0x00, 0x00, 0x00, 0x00,
    0x00, 0x00, 0x00, 0x00, 0x00, 0x00, 0x00, 0x00,
    0x00, 0x00, 0x00, 0x00, 0x00, 0x00, 0x00, 0x00,
    // TP - VERY SHORT for fast refresh!
    0x01, 0x01, 0x01, 0x01, 0x01, 0x01, 0x01, 0x01,
    0x01, 0x01, 0x01, 0x01, 0x01, 0x01, 0x01, 0x01,
    0x00, 0x00, 0x00, 0x00, 0x00, 0x00, 0x00, 0x00,
    0x00, 0x00, 0x00, 0x00, 0x00, 0x00, 0x00, 0x00,
    0x00, 0x00, 0x00, 0x00, 0x00, 0x00, 0x00, 0x00,
    0x00, 0x00, 0x00, 0x00, 0x00, 0x00, 0x00, 0x00,
    // RP
    0x00, 0x00, 0x00, 0x00, 0x00, 0x00, 0x00, 0x00,
    0x00, 0x00, 0x00, 0x00,
    // SR
    0x01, 0x01, 0x01, 0x01, 0x01, 0x01, 0x01, 0x01,
    0x01, 0x01, 0x01, 0x01, 0x01, 0x01, 0x01, 0x01,
    0x01, 0x01, 0x01, 0x01, 0x01, 0x01, 0x01, 0x01,
    // FR
    0x00, 0x00, 0x00, 0x00, 0x00, 0x00, 0x00, 0x00,
    0x00, 0x00, 0x00, 0x00,
    // XON
    0x00, 0x00, 0x00,
    // EOPT, Gate/Source/VCOM
    0x02, 0x00, 0x3F, 0x00, 0x00
};

static bool currentWaveformFast = false;

// Load waveform LUT to SSD1681
void loadWaveformLUT(const uint8_t* lut) {
    // Command 0x32: Write LUT register (153 bytes)
    digitalWrite(EPD_CS, LOW);
    digitalWrite(EPD_DC, LOW);
    SPI.transfer(0x32); // Write LUT
    digitalWrite(EPD_CS, HIGH);
    
    delayMicroseconds(10);
    
    // Send 153 bytes of LUT data
    digitalWrite(EPD_CS, LOW);
    digitalWrite(EPD_DC, HIGH);
    for (int i = 0; i < 153; i++) {
        SPI.transfer(lut[i]);
    }
    digitalWrite(EPD_CS, HIGH);
    
    Serial.println("[WF] LUT loaded");
}

// Apply waveform based on current state
void applyWaveform() {
    bool wantFast = (appState == AppState::MAIN_MENU || 
                    appState == AppState::COVER_FLOW || 
                    appState == AppState::SONG_LIST ||
                    appState == AppState::SETTINGS);
    
    if (wantFast != currentWaveformFast) {
        currentWaveformFast = wantFast;
        const uint8_t* lut = wantFast ? waveformFast : waveformFull;
        loadWaveformLUT(lut);
        Serial.printf("[WF] %s mode (state=%d)\n", wantFast ? "FAST" : "QUALITY", (int)appState);
    }
}

// ─────────────────────────────────────────────────────────────────
//  Charge Pump Voltage Control (SSD1681)
// ─────────────────────────────────────────────────────────────────
void applyChargePumpVoltage() {
    uint8_t vsh1;
    if (appState == AppState::NOW_PLAYING) {
        vsh1 = sysSettings.display.vsh1Media;
    } else {
        vsh1 = sysSettings.display.vsh1Menu;
    }
    
    uint8_t vsh2 = 50; // 5V
    uint8_t vsl = 0x32; // -15V
    
    digitalWrite(EPD_CS, LOW);
    digitalWrite(EPD_DC, LOW);
    SPI.transfer(0x04); // Command 0x04
    
    digitalWrite(EPD_DC, HIGH);
    SPI.transfer(vsh1);
    SPI.transfer(vsh2);
    SPI.transfer(vsl);
    digitalWrite(EPD_CS, HIGH);
    
    Serial.printf("[CP] VSH1=%d.%dV\n", vsh1/10, vsh1%10);
}

// ─────────────────────────────────────────────────────────────────
//  Power Management
// ─────────────────────────────────────────────────────────────────
void applyPowerSettings() {
    uint16_t freq = sysSettings.power.menuFreq;
    if (appState == AppState::NOW_PLAYING) freq = sysSettings.power.musicFreq;
    if (appState == AppState::USB_SYNC) freq = sysSettings.power.usbFreq;
    
    // Safeguard: WiFi/Web needs at least 80MHz to be stable
    if (freq < 80) {
        Serial.printf("[PWR] Freq %d too low for WiFi, forcing 80MHz\n", freq);
        freq = 80;
    }

    setCpuFrequencyMhz(freq);
    Serial.printf("[PWR] CPU Frequency set to %d MHz\n", freq);
}

void enterDeepSleep() {
    Serial.println("[PWR] Entering Deep Sleep...");
    
    // 1. Final Display Update
    display.setFullWindow();
    display.firstPage();
    do {
        display.fillScreen(GxEPD_WHITE);
        display.setFont(nullptr);
        display.setCursor(50, 100);
        display.print("SLEEPING... [BOOT TO WAKE]");
    } while (display.nextPage());
    
    // 2. Wait for E-Ink to finish drawing (critically important!)
    delay(1000); 

    // 3. Turn off LEDs and wait for task
    sysSettings.led.enabled = false;
    sysSettings.led.smoothness = false; // Disable smoothness for instant off
    LEDManager::getInstance().resetIdleTimer(); // Ensure task wakes if it was timed out
    delay(100); // Let LED task process it
    
    // Force clear for safety
    FastLED.clear();
    FastLED.show();
    
    // 4. Persistence
    SettingsManager::save(sd, sysSettings);
    
    // 5. Peripheral Sleep
    mpuManager.setSleep(true);
    SD_MMC.end(); // De-init SD
    
    // 6. Wakeup Setup (GPIO0 is BOOT button)
    esp_sleep_enable_ext0_wakeup(GPIO_NUM_0, 0); 
    
    Serial.flush();
    esp_deep_sleep_start();
}

void clearNpBgBitmap() {
    if (currentNpBgBitmap) {
        free(currentNpBgBitmap);
        currentNpBgBitmap = nullptr;
    }
}

// ─────────────────────────────────────────────────────────────────
//  Boot log (terminal style)
// ─────────────────────────────────────────────────────────────────
static int  logLine  = 0;
static const int LINE_H   = 14;
static const int MARGIN_X =  4;
static const int MARGIN_Y = 12;

void epd_log(const char* text) {
    if (logLine > 11) return;
    int y = MARGIN_Y + logLine++ * LINE_H;
    display.setPartialWindow(0, y - LINE_H + 2, 200, LINE_H);
    display.firstPage();
    do {
        display.fillScreen(GxEPD_BLACK);
        display.setFont(&FreeMonoBold9pt7b);
        display.setTextColor(GxEPD_WHITE);
        display.setCursor(MARGIN_X, y);
        display.print(text);
    } while (display.nextPage());
}

void printBanner() {
    display.setFullWindow();
    display.firstPage();
    do {
        display.fillScreen(GxEPD_BLACK);
        display.setFont(&FreeMonoBold9pt7b);
        display.setTextColor(GxEPD_WHITE);
        display.setCursor(MARGIN_X, MARGIN_Y);         display.print("NEBULA OS v0.1");
        display.setCursor(MARGIN_X, MARGIN_Y + LINE_H); display.print("----------------");
    } while (display.nextPage());
    logLine = 2;
}

// ─────────────────────────────────────────────────────────────────
//  SD + MediaDB
// ─────────────────────────────────────────────────────────────────
bool initSD() {
    SD_MMC.setPins(SD_MMC_CLK, SD_MMC_CMD, SD_MMC_D0);
    // Use 20MHz for stability in 1-bit mode, especially for MSC
    return SD_MMC.begin("/sd", true, false, 20000); 
}

void initMediaDB(bool forceRescan = false) {
    mediaDB.close();
    if (!forceRescan && mediaDB.open(sd)) {
        char buf[48];
        snprintf(buf, sizeof(buf), "DB: %lu tracks", mediaDB.trackCount());
        Serial.println(buf); epd_log(buf);
        return;
    }
    Serial.println("[DB] Building library...");
    epd_log("SCANNING SD...");

    uint32_t t0 = millis();
    uint32_t count = scanner.scan(sd, "/music");
    uint32_t elapsed = (millis() - t0) / 1000;

    char buf[48];
    if (count > 0) {
        snprintf(buf, sizeof(buf), "DB: %lu tracks (%lus)", count, elapsed);
        Serial.println(buf); epd_log(buf);
        mediaDB.open(sd);
    } else {
        epd_log("NO MUSIC FOUND!");
        Serial.println("[DB] No music found");
    }
}

// ─────────────────────────────────────────────────────────────────
//  Scene transitions
// ─────────────────────────────────────────────────────────────────
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
void loop() {
    uint32_t now = millis();

    // Auto-apply power profile and charge pump on state change
    static AppState lastState = AppState::BOOT;
    if (appState != lastState) {
        lastState = appState;
        applyPowerSettings();
        applyChargePumpVoltage();
        applyWaveform();
    }

    // Читати Serial або Web Remote
    char raw = 0;
    if (Serial.available()) {
        raw = Serial.read();
        while (Serial.available()) Serial.read();
    } else {
        raw = webManager.getRemoteKey();
    }

    if (raw != 0) {
        LEDManager::getInstance().resetIdleTimer();
    }


    // Глобальні команди
    if (raw == 'r') {
        Serial.println(">> Force rescan...");
        logLine = 0; printBanner();
        initMediaDB(true);
        switchToMenu();
        return;
    }
    if (raw == 'd') { dumpLibrary(); return; }

    // ── MAIN MENU ────────────────────────────────────────────────
    if (appState == AppState::MAIN_MENU) {
        if      (raw == '1') mainMenu.onPrev();
        else if (raw == '3') mainMenu.onNext();
        else if (raw == '2') {
            uint8_t sel = mainMenu.selectedIndex();
            if (sel == 0) { // MEDIA LIBRARY
                // If audio is playing in background, go back to NowPlaying directly
                if (audioPlayer.isPlaying() && currentAlbumTrackCount > 0) {
                    appState = AppState::NOW_PLAYING;
                    // Redraw NowPlaying with current track art
                    switchToNowPlaying(currentAlbumTracks[currentTrackIdx], currentTrackIdx);
                } else {
                    appState = AppState::COVER_FLOW;
                    coverFlow.setSettings(sysSettings);
                    coverFlow.setColors(CL_FG, CL_BG, sysSettings.display.skipArtInvert);
                    coverFlow.init(mediaDB, display, sd);
                    coverFlow.drawFull();
                }
            }
            else if (sel == 1) { /* TELEMETRY */ }
            else if (sel == 2) { /* EXTRAS */ }
            else if (sel == 3) { // SETTINGS
                appState = AppState::SETTINGS;
                settingsScene.init(display, sd, sysSettings);
                settingsScene.drawFull();
            }
        }
        else if (raw == '4') {
             // Redraw
             mainMenu.drawFull();
        }
    }

    // ── SETTINGS ────────────────────────────────────────────────
    else if (appState == AppState::SETTINGS) {
        if      (raw == '1') settingsScene.onUp();
        else if (raw == '3') settingsScene.onDown();
        else if (raw == '2') {
            settingsScene.onSelect();
            // Check if user selected WiFi Scanner
            if (settingsScene.wantsWiFiScan()) {
                appState = AppState::WIFI_SCANNER;
                wifiScene.init(display, sd, sysSettings, wifiScanner);
                wifiScene.startScan();
            }
            // Check if user selected WiFi Info
            if (settingsScene.wantsWiFiInfo()) {
                appState = AppState::WIFI_SCANNER;
                wifiScene.init(display, sd, sysSettings, wifiScanner);
                wifiScene.showInfo();
            }
            // Check if user selected WiFi QR
            if (settingsScene.wantsWiFiQR()) {
                appState = AppState::WIFI_SCANNER;
                wifiScene.init(display, sd, sysSettings, wifiScanner);
                wifiScene.showQRCode();
            }
            // Check if user selected SENSORS
            if (settingsScene.wantsSensors()) {
                appState = AppState::SENSORS;
                mpuManager.applySettings(sysSettings.mpu);
                sensorsScene.init(display, sysSettings, mpuManager);
                sensorsScene.drawFull();
            }
            if (settingsScene.wantsExplorer()) {
                appState = AppState::FILE_EXPLORER;
                explorerScene.init(display, sd, &sysSettings);
                explorerScene.drawFull();
            }
        }
        else if (raw == '4') {
            if (settingsScene.onBack()) {
                // Apply changes to all components immediately
                audioPlayer.applySettings(sysSettings);
                
                // === Bluetooth Dynamic Switch ===
                
                // ==============================

                mpuManager.applySettings(sysSettings.mpu);
                
                // Apply WiFi changes
                webManager.setWiFiEnabled(sysSettings.wifi.enabled);
                if (sysSettings.wifi.enabled) {
                    webManager.setWebEnabled(sysSettings.wifi.webEnabled);
                    webManager.setOTAEnabled(sysSettings.wifi.otaEnabled);
                }
                
                mainMenu.setColors(CL_FG, CL_BG);
                menu.setColors(CL_FG, CL_BG);
                coverFlow.setColors(CL_FG, CL_BG, sysSettings.display.skipArtInvert);
                nowPlaying.setColors(CL_FG, CL_BG);

                // Re-apply SPI freq if it was changed
                display.init(115200, false, sysSettings.display.spiFreqMhz, false); 

                appState = AppState::MAIN_MENU;
                mainMenu.drawFull();
            }
        }
        else if (raw == '5') {
            if (sysSettings.usb.mode == 0) {
                // SERIAL - Do nothing
            } else if (sysSettings.usb.mode == 1) {
                enterUsbSync();
            } else if (sysSettings.usb.mode == 2) {
                // FLASH (SLOWBOOT)
                uint8_t* flashBitmap = nullptr;
                File f = sd.open("/Bitmaps/Connect.bin", "r");
                if (f) {
                    flashBitmap = (uint8_t*)malloc(5000);
                    if (flashBitmap) f.read(flashBitmap, 5000);
                    f.close();
                }

                display.setFullWindow();
                display.firstPage();
                do {
                    if (flashBitmap) {
                        display.drawBitmap(0, 0, flashBitmap, 200, 200, CL_BG, CL_FG);
                    } else {
                        display.fillScreen(CL_BG);
                    }
                    display.fillRect(0, 0, 200, 25, CL_FG);
                    display.setFont(&FreeMonoBold9pt7b);
                    display.setTextColor(CL_BG);
                    
                    String title = "FIRMWARE FLASH";
                    int16_t x1, y1; uint16_t w, h;
                    display.getTextBounds(title.c_str(), 0, 0, &x1, &y1, &w, &h);
                    display.setCursor((200 - w) / 2, 18);
                    display.print(title);
                } while (display.nextPage());
                
                if (flashBitmap) free(flashBitmap);
                
                delay(1000);
                REG_WRITE(RTC_CNTL_OPTION1_REG, RTC_CNTL_FORCE_DOWNLOAD_BOOT);
                esp_restart();
            }
        }
    }

    // ── SENSORS ──────────────────────────────────────────────────
    else if (appState == AppState::SENSORS) {
        if      (raw == '1') sensorsScene.onUp();
        else if (raw == '3') sensorsScene.onDown();
        else if (raw == '2') sensorsScene.onSelect();
        else if (raw == '4') {
            if (sensorsScene.onBack()) {
                // Return to settings
                appState = AppState::SETTINGS;
                SettingsManager::save(sd, sysSettings);
                settingsScene.init(display, sd, sysSettings);
                settingsScene.drawFull();
            }
        }
        // Tick for 3D cube live updates
        sensorsScene.tick(now);
    }

    // ── FILE EXPLORER ────────────────────────────────────────────
    else if (appState == AppState::FILE_EXPLORER) {
        if      (raw == '1') explorerScene.onUp();
        else if (raw == '3') explorerScene.onDown();
        else if (raw == '2') explorerScene.onSelect();
        else if (raw == '4') {
            if (explorerScene.onBack()) {
                // Return to settings
                appState = AppState::SETTINGS;
                settingsScene.drawFull();
            }
        }
    }
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

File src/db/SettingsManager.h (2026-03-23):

#pragma once
#include <Arduino.h>
#include <FS.h>

enum PhaseInversionMode { PHASE_OFF, PHASE_LEFT, PHASE_RIGHT, PHASE_ALL };

struct AudioSettings {
    float    volume         = 0.05f;
    uint32_t sampleRate     = 44100;
    uint8_t  channels       = 2;
    uint8_t  bitsPerSample  = 16;
    uint16_t bufferSize     = 1024;
    uint16_t bufferCount    = 16;
    uint8_t  taskPriority   = 10;
    uint8_t  coreID         = 0;
    float    balance        = 0.0f; // -1.0 (Left) to 1.0 (Right)
    bool     backgroundMode = false; // Keep playing while navigating menus
    PhaseInversionMode phaseInversion = PHASE_OFF; // Phase inversion for psychoacoustic effects
};

struct DisplaySettings {
    bool     inverted       = false;
    bool     skipArtInvert  = true;
    bool     partialRefresh = true;
    bool     cfFullRefresh  = false;
    bool     softwareFullRefresh = false;
    uint8_t  softwareRefreshCycles = 1; // 1 to 5 cycles
    uint8_t  spiFreqMhz    = 4; // SPI clock: 2, 4, 8, 10, 20
    
    // Charge Pump Voltage Control (VSH1 in 0.1V units, range 24-170 = 2.4V-17V)
    uint8_t  vsh1Menu = 150;  // 15.0V for Menu
    uint8_t  vsh1Media = 150; // 15.0V for Media/NowPlaying
    uint8_t  vsh1Aod = 100;    // 10.0V for AOD (lower = less power)
};

struct UsbSettings {
    int      mode         = 1;     // 0=SERIAL, 1=STORAGE, 2=FLASH
    int      chunkSectors = 128;   // 64, 128, 256
    uint32_t freqKhz      = 40000; // 20000, 40000, 80000
};

struct MPU6050Settings {
    uint8_t  accelRange   = 0;     // 0=±2g, 1=±4g, 2=±8g, 3=±16g
    uint8_t  gyroRange    = 0;     // 0=±250, 1=±500, 2=±1000, 3=±2000 °/s
    bool     invertX      = false;
    bool     invertY      = false;
    bool     invertZ      = false;
    bool     dmpEnabled   = false;
};

struct RGBColor {
    uint8_t r = 255;
    uint8_t g = 100;
    uint8_t b = 50;
};

enum LEDMode { MODE_SOLID, MODE_KELVIN, MODE_RAINBOW };

struct LEDSettings {
    bool     enabled      = true;
    uint8_t  brightness   = 50;  // 0-100%
    uint8_t  mode         = MODE_KELVIN;
    uint16_t kelvin       = 3500;
    RGBColor solidColor;
    bool     smoothness   = true;
    uint8_t  fadeSpeed    = 50;  // 1-255
    uint16_t autoOffSec   = 300; // 5 mins
};

struct PowerSettings {
    uint16_t menuFreq    = 240; // Default max
    uint16_t musicFreq   = 160;
    uint16_t usbFreq     = 80;
};

struct WiFiSettings {
    bool enabled        = true;   // WiFi ввімкнено/вимкнено
    bool webEnabled     = true;   // Веб-інтерфейс увімкнено
    bool otaEnabled     = false;  // OTA прошивка увімкнено
    bool autoConnect    = true;   // Автоматичне підключення при старті
    char savedSSID[32];           // Збережений SSID
    char savedPassword[64];        // Збережений пароль
};

struct BluetoothSettings {
    bool receiverMode = false;
};

struct SystemSettings {
    AudioSettings     audio;
    DisplaySettings   display;
    UsbSettings       usb;
    MPU6050Settings   mpu;
    LEDSettings       led;
    PowerSettings     power;
    WiFiSettings      wifi;
    BluetoothSettings bluetooth;
};

// Bump this whenever SystemSettings struct layout changes
static constexpr uint32_t SETTINGS_VERSION = 7; // Bumped for software full refresh

struct SettingsFileHeader {
    uint32_t magic;   // 0xNEBULA01
    uint32_t version; // SETTINGS_VERSION
    uint32_t size;    // sizeof(SystemSettings)
};
static constexpr uint32_t SETTINGS_MAGIC = 0xEB010001;
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

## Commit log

2026-01-20 Update README with additional images
    Added an additional image to the README for the PCB and 3D render.
2026-01-20 Шось обновив надеюсь не сломалось
    [Drill_NPTH_Through.DRL, Drill_PTH_Through.DRL, Gerber_BoardOutlineLayer.GKO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]
2026-01-20 добавив фоткі плати
    [BOM_PCB2_PCB1_2026-01-20.xlsx]
2026-01-20 Fix formatting in README.md for Power System section
2026-03-04 ws2812, setings fix, web control, save settings
    [MPU6050Manager.h, SettingsManager.h, SettingsScene.h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]
2026-03-10 feat: Implement comprehensive WiFi management including scanning, connection, OTA updates, and dedicated UI.
    [diff.csv, results.csv]

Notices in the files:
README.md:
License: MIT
